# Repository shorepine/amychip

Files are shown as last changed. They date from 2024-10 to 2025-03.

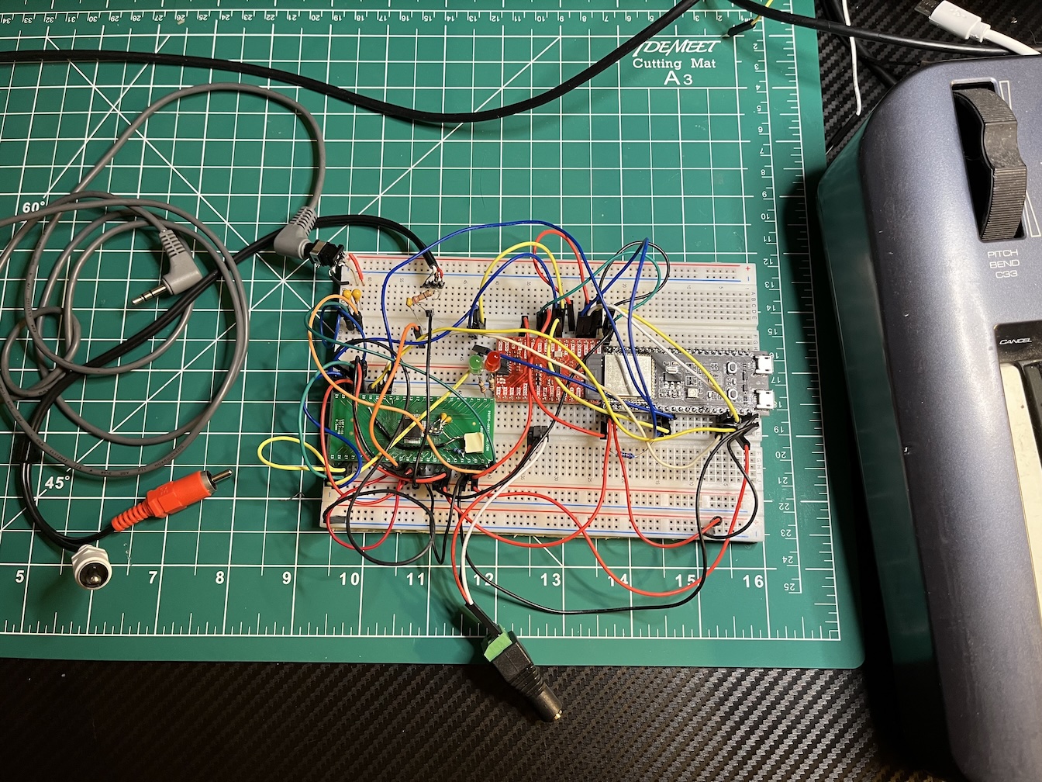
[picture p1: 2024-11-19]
images/pcm9211_hookup.jpeg

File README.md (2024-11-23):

# AMY on a chip 

This repository collects "AMYchip" implementations, where we run the [AMY](https://github.com/shorepine/AMY) synthesizer on a full chip (doing nothing else), servicing requests over i2c (and future, SPI etc).

We have
 - [`esp32s3`](https://github.com/shorepine/amychip/tree/main/esp32s3)

And soon want to have
 - `rp2350`
 - `esp32p4`
 - `daisy`

## How to

Set your I2S and I2C pins at the top of the `amychip.c` in your chip's folder:

```c
#define I2S_BCLK 13 
#define I2S_LRCLK 12
#define I2S_DIN 11 // data going to the codec, eg DAC data
#define I2C_SLAVE_SCL 5  
#define I2C_SLAVE_SDA 4 
#define I2C_MASTER_SCL 17
#define I2C_MASTER_SDA 18
#define I2S_DOUT 16 // data coming from the codec, eg ADC  data
```

Set up your DAC / ADC codec. I'm using the [`WM8960`](https://www.sparkfun.com/products/21250) codec. Wire it up like:

```
Tulip or etc I2C/Mabee/Grove SCL -> I2C_SLAVE_SCL
Tulip or etc I2C/Mabee/Grove SDA -> I2C_SLAVE_SDA
Tulip or etc I2C/Mabee/Grove GND -> MCU GND
Tulip or etc I2C/Mabee/Grove 3.3V -> MCU 3V3
USB 5V -> MCU (we need 5V to power this codec)
WM8960 GND -> Audio in sleeve/GND
WM8960 LINPUT1 -> Audio in L
WM8960 RINPUT1 -> Audio in R
WM8960 HPL -> Audio out L
WM8960 OUT3 -> Audio out sleeve  *** NOTE: Audio-out "ground" is actually a special "mid-voltage" on OUT3
WM8960 HPR -> Audio out R
WM8960 BLCK -> I2S_BCLK
WM8960 DACLRC -> I2S_LRCLK (shared)
WM8960 DACDAT -> I2S_DIN
WM8960 ADCLRC -> I2S_LRCLK (shared)
WM8960 ADCDAT -> I2S_DOUT
WM8960 SCL -> I2C_MASTER_SCL
WM8960 SDA -> I2C_MASTER_SDA
WM8960 3V3 -> MCU 3V3
WM8960 VIN -> MCU 5V 
WM8960 GND -> MCU GND 
```

Compile / flash `amychip` using the instructions in the chip's folder.

Control the chip over I2C. In e.g. Tulip, that's as simple as 

```python
from machine import I2C
import amy
i2c = I2C(0, freq=400000)

amy.override_send= lambda x : i2c.writeto(0x58, bytes(x.encode('ascii')))
amy.send(reset=amy.RESET_TIMEBASE, time=tulip.ticks_ms()) # Restart the clock
```

You can get this on Tulip World:

```python
world.download('amychip.py')
execfile('amychip.py')
```

## Protocol

For now, over i2c, we just send AMY messages encoded as ASCII to `0x58`. Nothing gets returned. 

TODO:
 - ~~`memorypcm` / sample loading~~
 - stderr feedback over I2C
 - `sequencer.c`, sending interrupts to the "main" i2c host
 - SPI? UART?

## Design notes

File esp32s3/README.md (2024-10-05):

# AMY on a chip 

An ESP-IDF implementation of running [AMY](https://github.com/shorepine/AMY) on a full chip 

[See the main README for setup instructions.](https://github.com/shorepine/amychip/blob/main/README.md)

## ESP32-S3 setup

Install and export the [ESP-IDF](https://github.com/espressif/esp-idf). Use the `master` branch.  You will likely need version 5.4; version 5.2 does not work, so install this new version even if you have an existing, older one installed.

```bash
git clone https://github.com/espressif/esp-idf
cd esp-idf
./install.sh esp32s3
source ./export.sh
cd ..
```

Compile and flash your AMY board

```bash
cd amychip
idf.py set-target esp32s3
cd esp32s3
idf.py flash
```

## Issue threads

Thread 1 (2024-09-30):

import amychip fails

phesterman, 2024-09-30:
I successfully built and flashed amychip to my esp32s3.

Then, I followed these instructions:
```
from machine import I2C
import amy
i2c = I2C(0, freq=400000)

amy.override_send= lambda x : i2c.writeto(0x58, bytes(x.encode('ascii')))
```

I downloaded amychip.py from tulip world.

When I import amychip:

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

Where did I mess it up?  (My Tulip is up to date.)

Closed 2024-10-01.

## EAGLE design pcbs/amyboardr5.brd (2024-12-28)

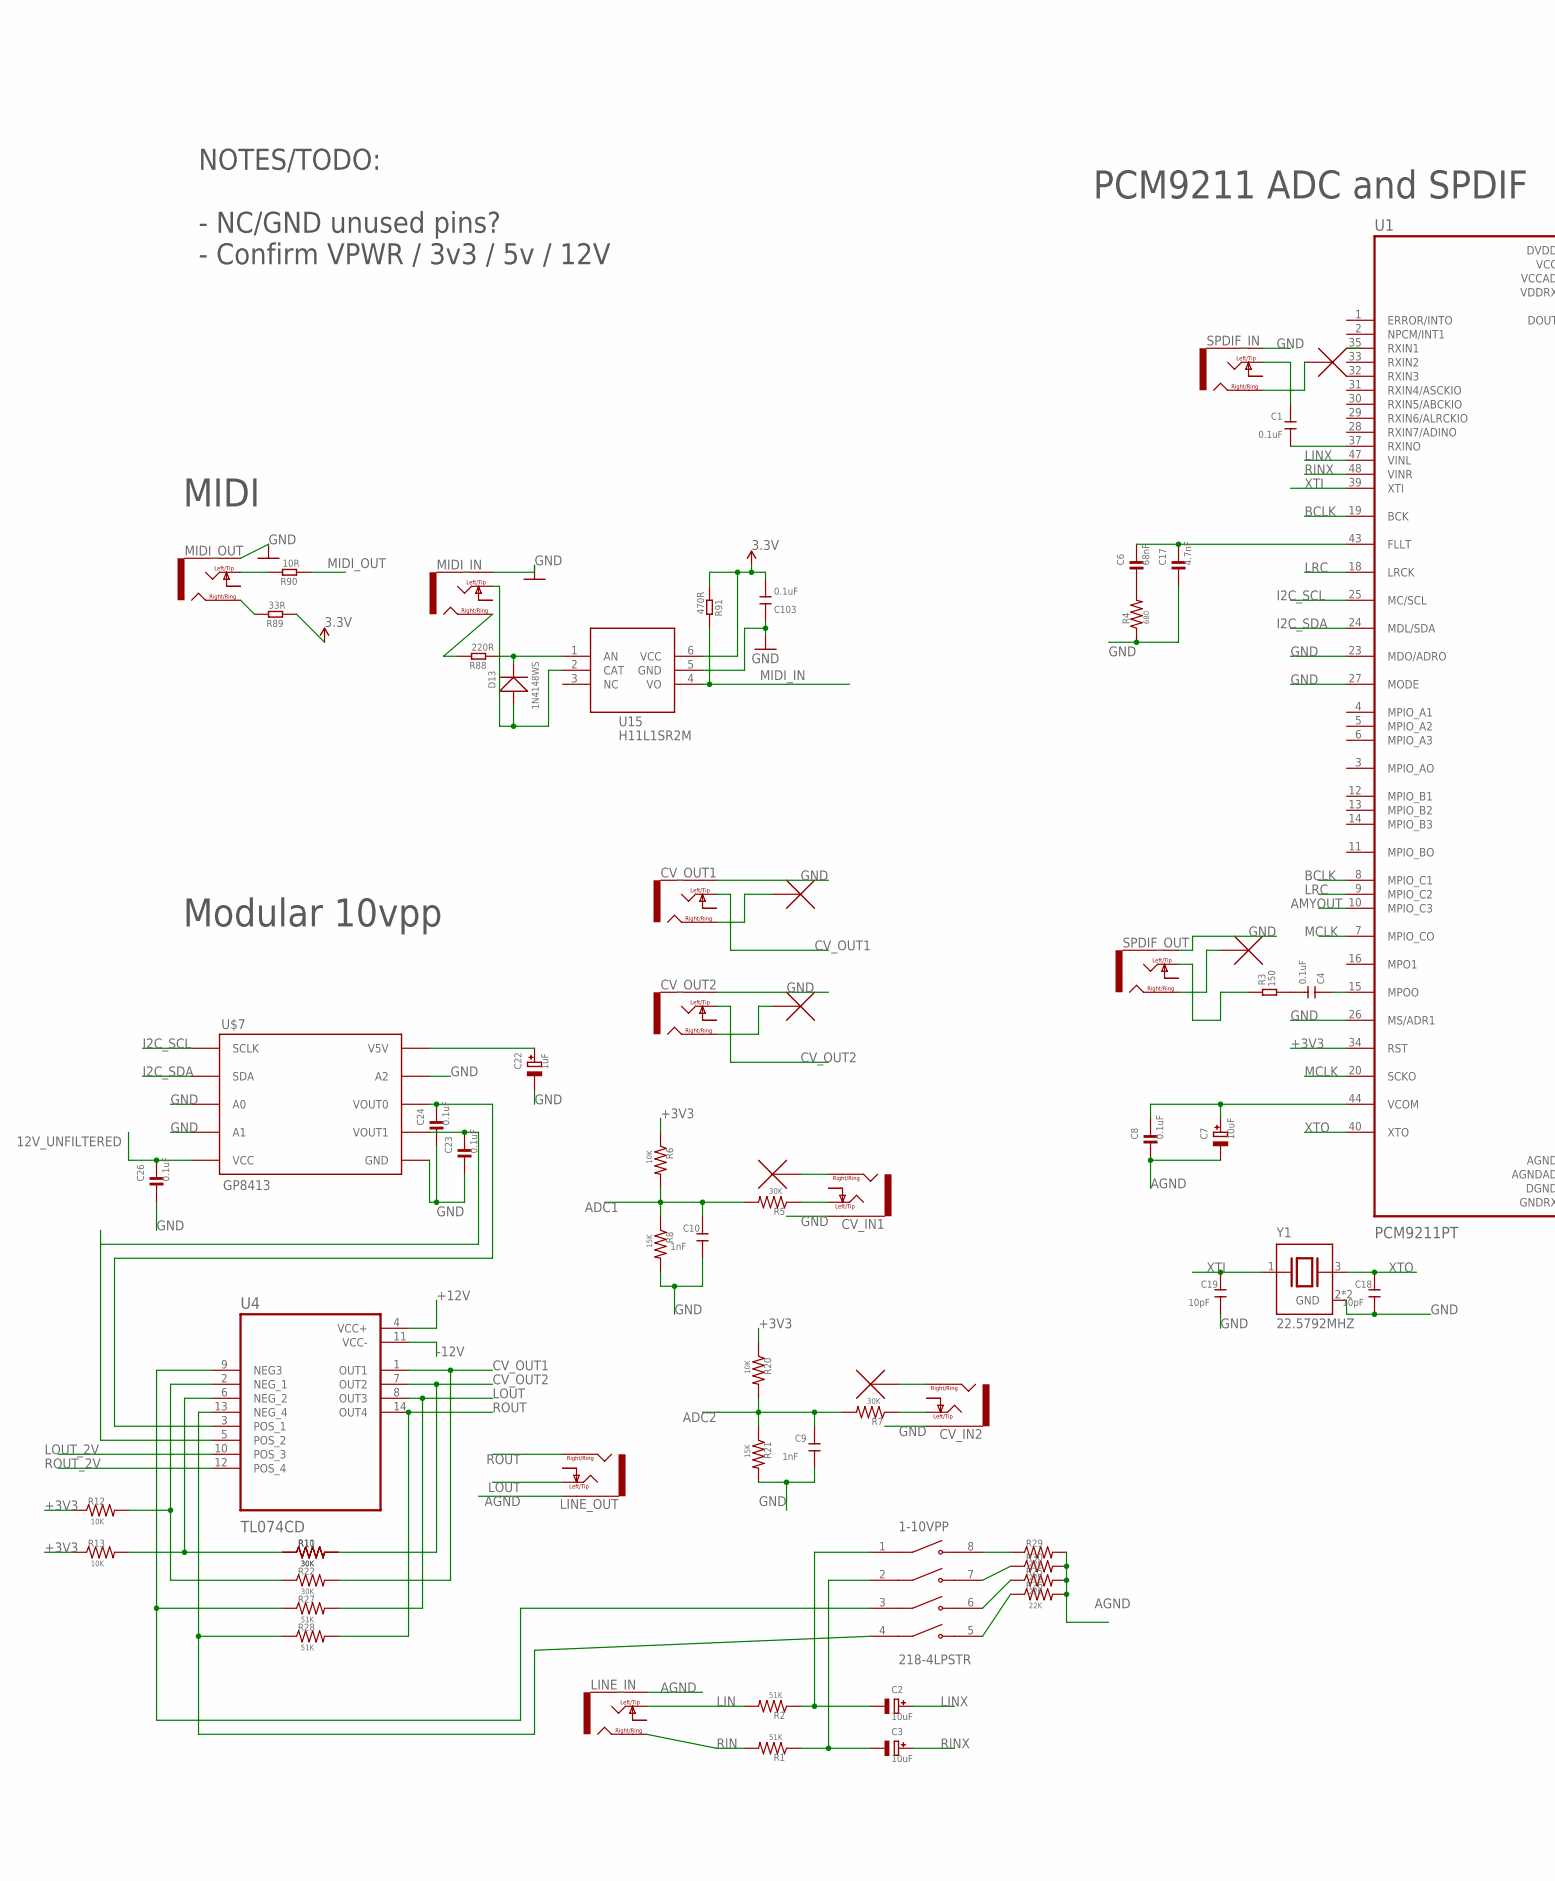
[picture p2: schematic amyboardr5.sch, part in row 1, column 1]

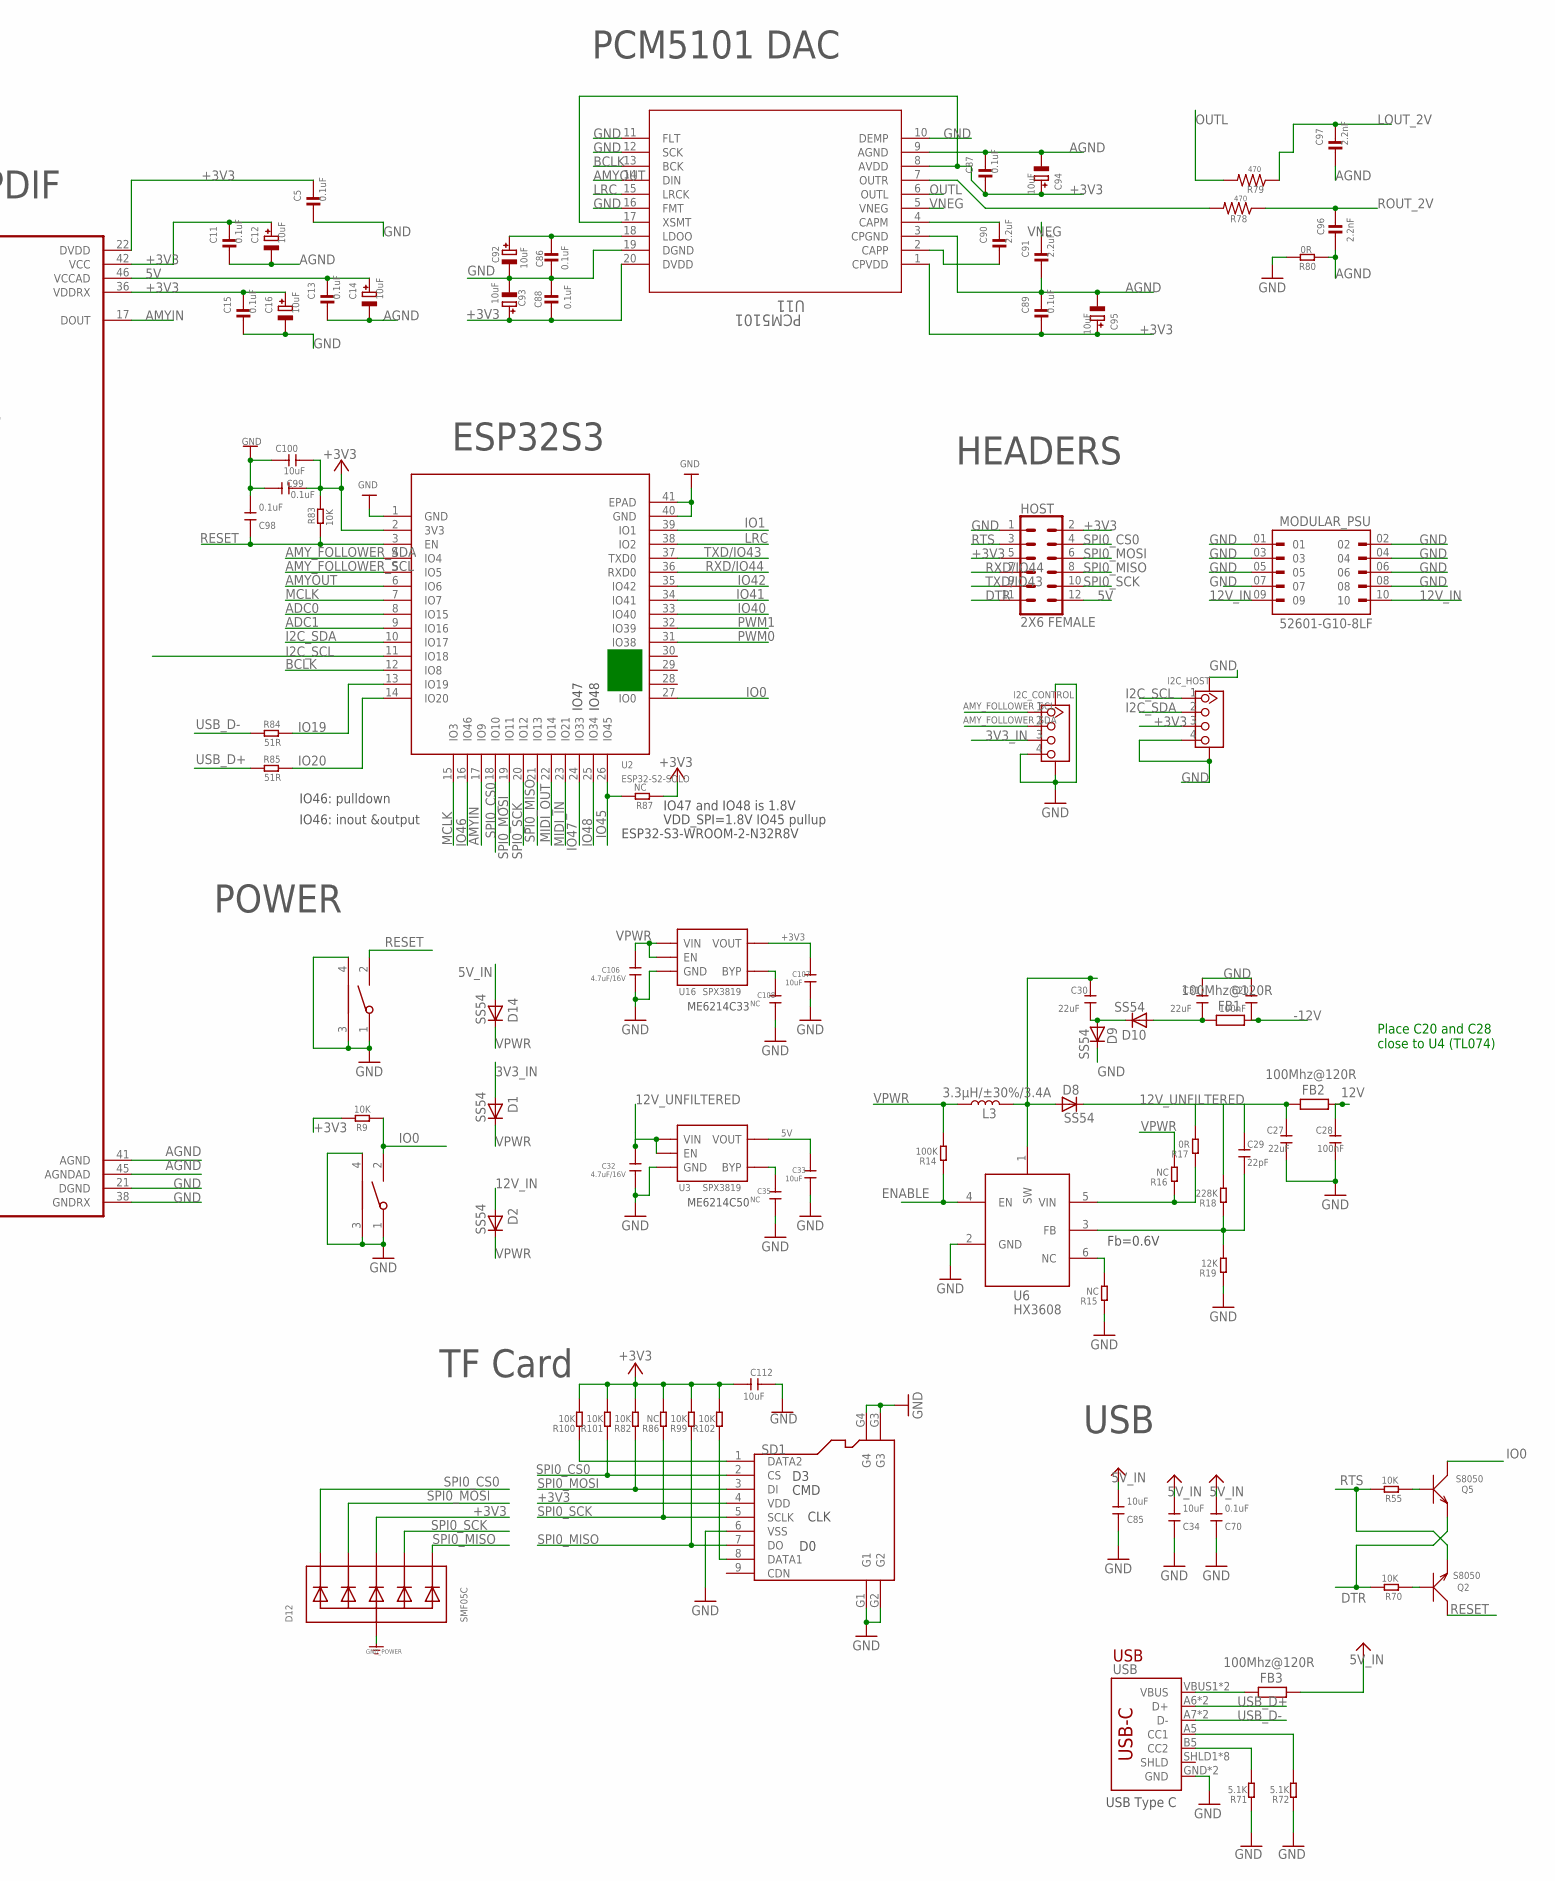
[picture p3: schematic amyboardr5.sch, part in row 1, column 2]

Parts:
1-10VPP: 218-4LPSTR; SW_218-4LPSTR
BOOT: TS24CA; 2*4*3.5MM
C1, C4: 0.1uF; C0603
C2, C3, C7, C12, C14, C16, C92, C93, C94, C95: 10uF; PANASONIC_C
C5, C8, C11, C13, C15, C23, C24, C26, C86, C87, C88, C89: 0.1uF; 0805-NO@1
C6: 68nF; 0805-NO@1
C9, C10: 1nF; C0603
C17: 4.7nF; 0805-NO@1
C18, C19: 10pF; C0603
C20, C28: 100nF; C0603
C22: 1uF; PANASONIC_C
C27, C30, C31: 22uF; C0603
C29: 22pF; C0603
C32, C106: 4.7uF/16V; 0603
C33, C107: 10uF; 0603
C34, C85, C100, C112: 10uF; DISCRETE_C0603
C35, C108: NC; 0603
C70, C98, C99, C103: 0.1uF; DISCRETE_C0603
C90, C91: 2.2uF; 0805-NO@1
C96, C97: 2.2nF; 0805-NO@1
CV_IN1, CV_IN2: NV-PJ3410_STEREO; NV-PJ3410_SOCKET
CV_OUT1, CV_OUT2: NV-PJ3410_STEREO; NV-PJ3410_SOCKET
D1, D2, D8, D9, D10, D14: SS54; DO-214AC
D12: SMF05C; SOT363
D13: 1N4148WS; SOD323
FB1, FB2, FB3: 100Mhz@120R; R0805
HOST: 2X6 FEMALE; 2X6
I2C_CONTROL, I2C_HOST: GROVE-CONNECTOR-SMD'90D'; HW4-SMD-2.0-90D
L3: 3.3µH/±30%/3.4A; CR54
LINE_IN: NV-PJ3410_STEREO; NV-PJ3410_SOCKET
LINE_OUT: NV-PJ3410_STEREO; NV-PJ3410_SOCKET
MIDI_IN: NV-PJ3410_STEREO; NV-PJ3410_SOCKET
MIDI_OUT: NV-PJ3410_STEREO; NV-PJ3410_SOCKET
MODULAR_PSU: 52601-G10-8LF; AMPHENOL_52601-G10-8LF
PCM5101: U11; PW20_TEX
Q2, Q5: S8050; SOT23
R1, R2, R27, R28: 51K; R0805
R3: 150; DISCRETE_R0603
R4: 680; R0805
R5, R7, R10, R11, R22: 30K; R0805
R6, R12, R13, R20: 10K; R0805
R8, R21: 15K; R0805
R9, R55, R70, R83: 10K; R0603
R14: 100K; DISCRETE_R0603
R15, R16, R86: NC; DISCRETE_R0603
R17, R80: 0R; DISCRETE_R0603
R18: 228K; DISCRETE_R0603
R19: 12K; DISCRETE_R0603
R25, R26, R29, R30: 22K; R0805
R71, R72: 5.1K; DISCRETE_R0603
R78, R79: 470; R0805
R82, R99, R100, R101, R102: 10K; DISCRETE_R0603
R84, R85: 51R; R0603
R87: NC; R0603
R88: 220R; R0603
R89: 33R; R0603
R90: 10R; R0603
R91: 470R; R0603
RST: TS24CA; 2*4*3.5MM
SD1: HOLDER-MICROSD-9P; 9P-SMD-W/-RING
SPDIF_IN: NV-PJ3410_STEREO; NV-PJ3410_SOCKET
SPDIF_OUT: NV-PJ3410_STEREO; NV-PJ3410_SOCKET
U1: PCM9211PT; QFP50P900X900X160-48N
U2: ESP32­S2­SOLO; ESP32-­S2-­SOLO
U3, U16: SPX3819; SOT23-5
U4: TL074CD; SOIC127P600X175-14N
U6: HX3608; SOT-23-6
U15: H11L1SR2M; SOP-6-2.54MM
U$7: GP8413; SOIC-10
USB: USB_C5; USB-C-16P-5
Y1: 22.5792MHZ; XTAL_ABM10W-22.5792MHZ-8-K1Z-T3

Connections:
3.3V: C103.2, R89.1, R91.1, U15.6 (VCC)
3V3_IN: D1.A, I2C_CONTROL.3
5V: C13.1, C14.+, C33.1, HOST.12, U1.46 (VCCAD), U3.5 (VOUT)
5V_IN: C34.2, C70.2, C85.2, D14.A, FB3.2
12V: C28.1, FB2.2, R17.2
12V_IN: D2.A, MODULAR_PSU.09, MODULAR_PSU.10
12V_UNFILTERED: C26.1, C27.1, C32.1, D8.C, FB2.1, U3.1 (VIN), U3.3 (EN), U$7.5 (VCC)
+3V3: C5.1, C11.1, C12.+, C15.1, C16.+, C87.2, C88.2, C89.2, C93.+, C94.+, C95.+, C99.1, C100.1, C107.1, C112.2, D12.4 (C3), HOST.2, HOST.5, I2C_HOST.3, PCM5101.1 (CPVDD), PCM5101.8 (AVDD), PCM5101.17 (XSMT), PCM5101.20 (DVDD), R6.1, R9.2, R12.1, R13.1, R20.1, R82.2, R83.2, R86.2, R87.1, R99.2, R100.2, R101.2, R102.2, SD1.4 (VDD), U1.22 (DVDD), U1.34 (RST), U1.36 (VDDRX), U1.42 (VCC), U2.2 (3V3), U16.5 (VOUT)
+12V: U4.4 (VCC+)
-12V: C20.2, FB1.2, U4.11 (VCC-)
ADC0: U2.8 (IO15)
ADC1: C10.1, R5.2, R6.2, R8.1, U2.9 (IO16)
ADC2: C9.1, R7.2, R20.2, R21.1
AGND: C7.-, C8.2, C11.2, C12.-, C13.2, C14.-, C87.1, C89.1, C91.2, C94.-, C95.-, C96.2, C97.2, LINE_IN.GND (EARTH), LINE_OUT.GND (EARTH), PCM5101.3 (CPGND), PCM5101.9 (AGND), R25.2, R26.2, R29.2, R30.2, R80.1, U1.41 (AGND), U1.45 (AGNDAD)
AMYIN: U1.17 (DOUT), U2.17 (IO9)
AMYOUT: PCM5101.14 (DIN), U1.10 (MPIO_C3), U2.6 (IO6)
AMY_FOLLOWER_SCL: I2C_CONTROL.1, U2.5 (IO5)
AMY_FOLLOWER_SDA: I2C_CONTROL.2, U2.4 (IO4)
BCLK: PCM5101.13 (BCK), U1.8 (MPIO_C1), U1.19 (BCK), U2.12 (IO8)
CV_OUT1: CV_OUT1.LEFT/TIP (TIP), R22.2, U4.1 (OUT1)
CV_OUT2: CV_OUT2.LEFT/TIP (TIP), R10.2, R11.2, U4.7 (OUT2)
DTR: HOST.11, Q5.2 (E), R70.2
ENABLE: R14.1, U6.4 (EN)
GND: BOOT.1, BOOT.3, BOOT.4, C5.2, C9.2, C10.2, C15.2, C16.-, C17.2, C18.2, C19.2, C20.1, C22.-, C23.2, C24.2, C26.2, C27.2, C28.2, C31.1, C32.2, C33.2, C34.1, C35.2, C70.1, C85.1, C86.2, C88.1, C92.-, C93.-, C98.2, C99.2, C100.2, C103.1, C106.2, C107.2, C108.2, C112.1, CV_IN1.GND (EARTH), CV_IN2.GND (EARTH), CV_OUT1.GND (EARTH), CV_OUT2.GND (EARTH), D9.C, D12.2 (A), HOST.1, I2C_CONTROL.4, I2C_CONTROL.SS1, I2C_CONTROL.SS2, I2C_HOST.4, I2C_HOST.SS1, I2C_HOST.SS2, MIDI_IN.GND (EARTH), MIDI_OUT.GND (EARTH), MODULAR_PSU.01, MODULAR_PSU.02, MODULAR_PSU.03, MODULAR_PSU.04, MODULAR_PSU.05, MODULAR_PSU.06, MODULAR_PSU.07, MODULAR_PSU.08, PCM5101.10 (DEMP), PCM5101.11 (FLT), PCM5101.12 (SCK), PCM5101.16 (FMT), PCM5101.19 (DGND), R4.1, R8.2, R15.1, R19.1, R21.2, R71.1, R72.1, R80.2, RST.1, RST.3, RST.4, SD1.6 (VSS), SD1.G1, SD1.G2, SD1.G3, SD1.G4, SPDIF_IN.GND (EARTH), SPDIF_OUT.GND (EARTH), U1.21 (DGND), U1.23 (MDO/ADRO), U1.26 (MS/ADR1), U1.27 (MODE), U1.35 (RXIN1), U1.38 (GNDRX), U2.1 (GND), U2.40 (GND), U2.41 (EPAD), U3.2 (GND), U6.2 (GND), U15.5 (GND), U16.2 (GND), U$7.3 (A0), U$7.4 (A1), U$7.6 (GND), U$7.9 (A2), USB.GND, USB.GND2 (GND), Y1.2 (GND), Y1.4 (GND)
I2C_SCL: I2C_HOST.1, U1.25 (MC/SCL), U2.11 (IO18), U$7.1 (SCLK)
I2C_SDA: I2C_HOST.2, U1.24 (MDL/SDA), U2.10 (IO17), U$7.2 (SDA)
IO0: BOOT.2, Q5.3 (C), R9.1, U2.27 (IO0)
IO1: U2.39 (IO1)
IO19: R84.2, U2.13 (IO19)
IO20: R85.2, U2.14 (IO20)
IO40: U2.33 (IO40)
IO41: U2.34 (IO41)
IO42: U2.35 (IO42)
IO45: R87.2, U2.26 (IO45)
IO46: U2.16 (IO46)
IO47: U2.24 (IO33)
IO48: U2.25 (IO34)
LIN: LINE_IN.LEFT/TIP (TIP), R2.2
LINX: C2.+, U1.47 (VINL)
LOUT: LINE_OUT.LEFT/TIP (TIP), R27.2, U4.8 (OUT3)
LOUT_2V: C97.1, R79.1, U4.10 (POS_3)
LRC: PCM5101.15 (LRCK), U1.9 (MPIO_C2), U1.18 (LRCK), U2.38 (IO2)
MCLK: U1.7 (MPIO_CO), U1.20 (SCKO), U2.7 (IO7), U2.15 (IO3)
MIDI_IN: R91.2, U2.23 (IO21), U15.4 (VO)
MIDI_OUT: R90.1, U2.22 (IO14)
unnamed: C1.2, U1.37 (RXINO)
unnamed: C4.2, R3.2
unnamed: C4.1, U1.15 (MPOO)
unnamed: 1-10VPP.1, C2.-, R2.1
unnamed: 1-10VPP.2, C3.-, R1.1
unnamed: C7.+, C8.1, U1.44 (VCOM)
unnamed: C6.1, C17.1, U1.43 (FLLT)
unnamed: C6.2, R4.2
unnamed: CV_IN2.LEFT/TIP (TIP), R7.1
unnamed: C35.1, U3.4 (BYP)
unnamed: C31.2, D10.A, FB1.1
unnamed: C24.1, U4.3 (POS_1), U$7.8 (VOUT0)
unnamed: CV_IN1.LEFT/TIP (TIP), R5.1
unnamed: C23.1, U4.5 (POS_2), U$7.7 (VOUT1)
unnamed: C30.1, D8.A, L3.P$2 (2), U6.1 (SW)
unnamed: C22.+, U$7.10 (V5V)
unnamed: C29.2, R18.1, R19.2, U6.3 (FB)
unnamed: R15.2, U6.6 (NC)
unnamed: R16.1, R17.1, U6.5 (VIN)
unnamed: C30.2, D9.A, D10.C
unnamed: R10.1, R11.1, R13.2, U4.6 (NEG_2)
unnamed: R12.2, R22.1, U4.2 (NEG_1)
unnamed: Q2.1 (B), R70.1
unnamed: 1-10VPP.5, R26.1
unnamed: 1-10VPP.6, R25.1
unnamed: Q5.1 (B), R55.1
unnamed: R72.2, USB.A5 (CC1)
unnamed: R71.2, USB.B5 (CC2)
unnamed: 1-10VPP.8, R29.1
unnamed: 1-10VPP.7, R30.1
unnamed: FB3.1, USB.VBUS1 (VBUS), USB.VBUS2 (VBUS)
unnamed: 1-10VPP.3, R27.1, U4.9 (NEG3)
unnamed: 1-10VPP.4, R28.1, U4.13 (NEG_4)
unnamed: C86.1, C92.+, PCM5101.18 (LDOO)
unnamed: PCM5101.7 (OUTR), R78.2
unnamed: C90.1, PCM5101.4 (CAPM)
unnamed: C90.2, PCM5101.2 (CAPP)
unnamed: D13.+, MIDI_IN.LEFT/TIP (TIP), U15.2 (CAT)
unnamed: MIDI_IN.RIGHT/RING (RING), R88.2
unnamed: D13.-, R88.1, U15.1 (AN)
unnamed: MIDI_OUT.LEFT/TIP (TIP), R90.2
unnamed: MIDI_OUT.RIGHT/RING (RING), R89.2
unnamed: C108.1, U16.4 (BYP)
unnamed: R100.1, SD1.1 (DATA2)
unnamed: R102.1, SD1.8 (DATA1)
OUTL: PCM5101.6 (OUTL), R79.2
PWM0: U2.31 (IO38)
PWM1: U2.32 (IO39)
RESET: C98.1, Q2.3 (C), R83.1, RST.2, U2.3 (EN)
RIN: LINE_IN.RIGHT/RING (RING), R1.2
RINX: C3.+, U1.48 (VINR)
ROUT: LINE_OUT.RIGHT/RING (RING), R28.2, U4.14 (OUT4)
ROUT_2V: C96.1, R78.1, U4.12 (POS_4)
RTS: HOST.3, Q2.2 (E), R55.2
RXD/IO44: HOST.7, U2.36 (RXD0)
SPDIFIN_SIGNAL: C1.1, SPDIF_IN.LEFT/TIP (TIP)
SPDIFOUT_SIGNAL: R3.1, SPDIF_OUT.LEFT/TIP (TIP)
SPI0_CS0: D12.1 (C1), HOST.4, R101.1, SD1.2 (CS), U2.18 (IO10)
SPI0_MISO: D12.6 (C5), HOST.8, R99.1, SD1.7 (DO), U2.21 (IO13)
SPI0_MOSI: D12.3 (C2), HOST.6, R82.1, SD1.3 (DI), U2.19 (IO11)
SPI0_SCK: D12.5 (C4), HOST.10, R86.1, SD1.5 (SCLK), U2.20 (IO12)
TXD/IO43: HOST.9, U2.37 (TXD0)
USB_D+: R85.1, USB.A6 (D+), USB.B6 (D+)
USB_D-: R84.1, USB.A7 (D-), USB.B7 (D-)
VNEG: C91.1, PCM5101.5 (VNEG)
VPWR: C106.1, D1.C, D2.C, D14.C, L3.P$1 (1), R14.2, R16.2, U16.1 (VIN), U16.3 (EN)
XTI: C19.1, U1.39 (XTI), Y1.1
XTO: C18.1, U1.40 (XTO), Y1.3 (2)

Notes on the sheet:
USB
USB Type C
IO46: pulldown
IO46: inout &output
ESP32-S3-WROOM-2-N32R8V
IO47
IO48
IO47 and IO48 is 1.8V
VDD_SPI=1.8V IO45 pullup
POWER
ME6214C33
MIDI
PCM9211 ADC and SPDIF
ESP32S3
HEADERS
NOTES/TODO: - NC/GND unused pins? - Confirm VPWR / 3v3 / 5v / 12V
TF Card
CMD
CLK
Modular 10vpp
Fb=0.6V
ME6214C50
PCM5101 DAC
Place C20 and C28 close to U4 (TL074)

Board: 2 copper layers, 147 parts (11 on the bottom side), 102 nets, no tracks yet.

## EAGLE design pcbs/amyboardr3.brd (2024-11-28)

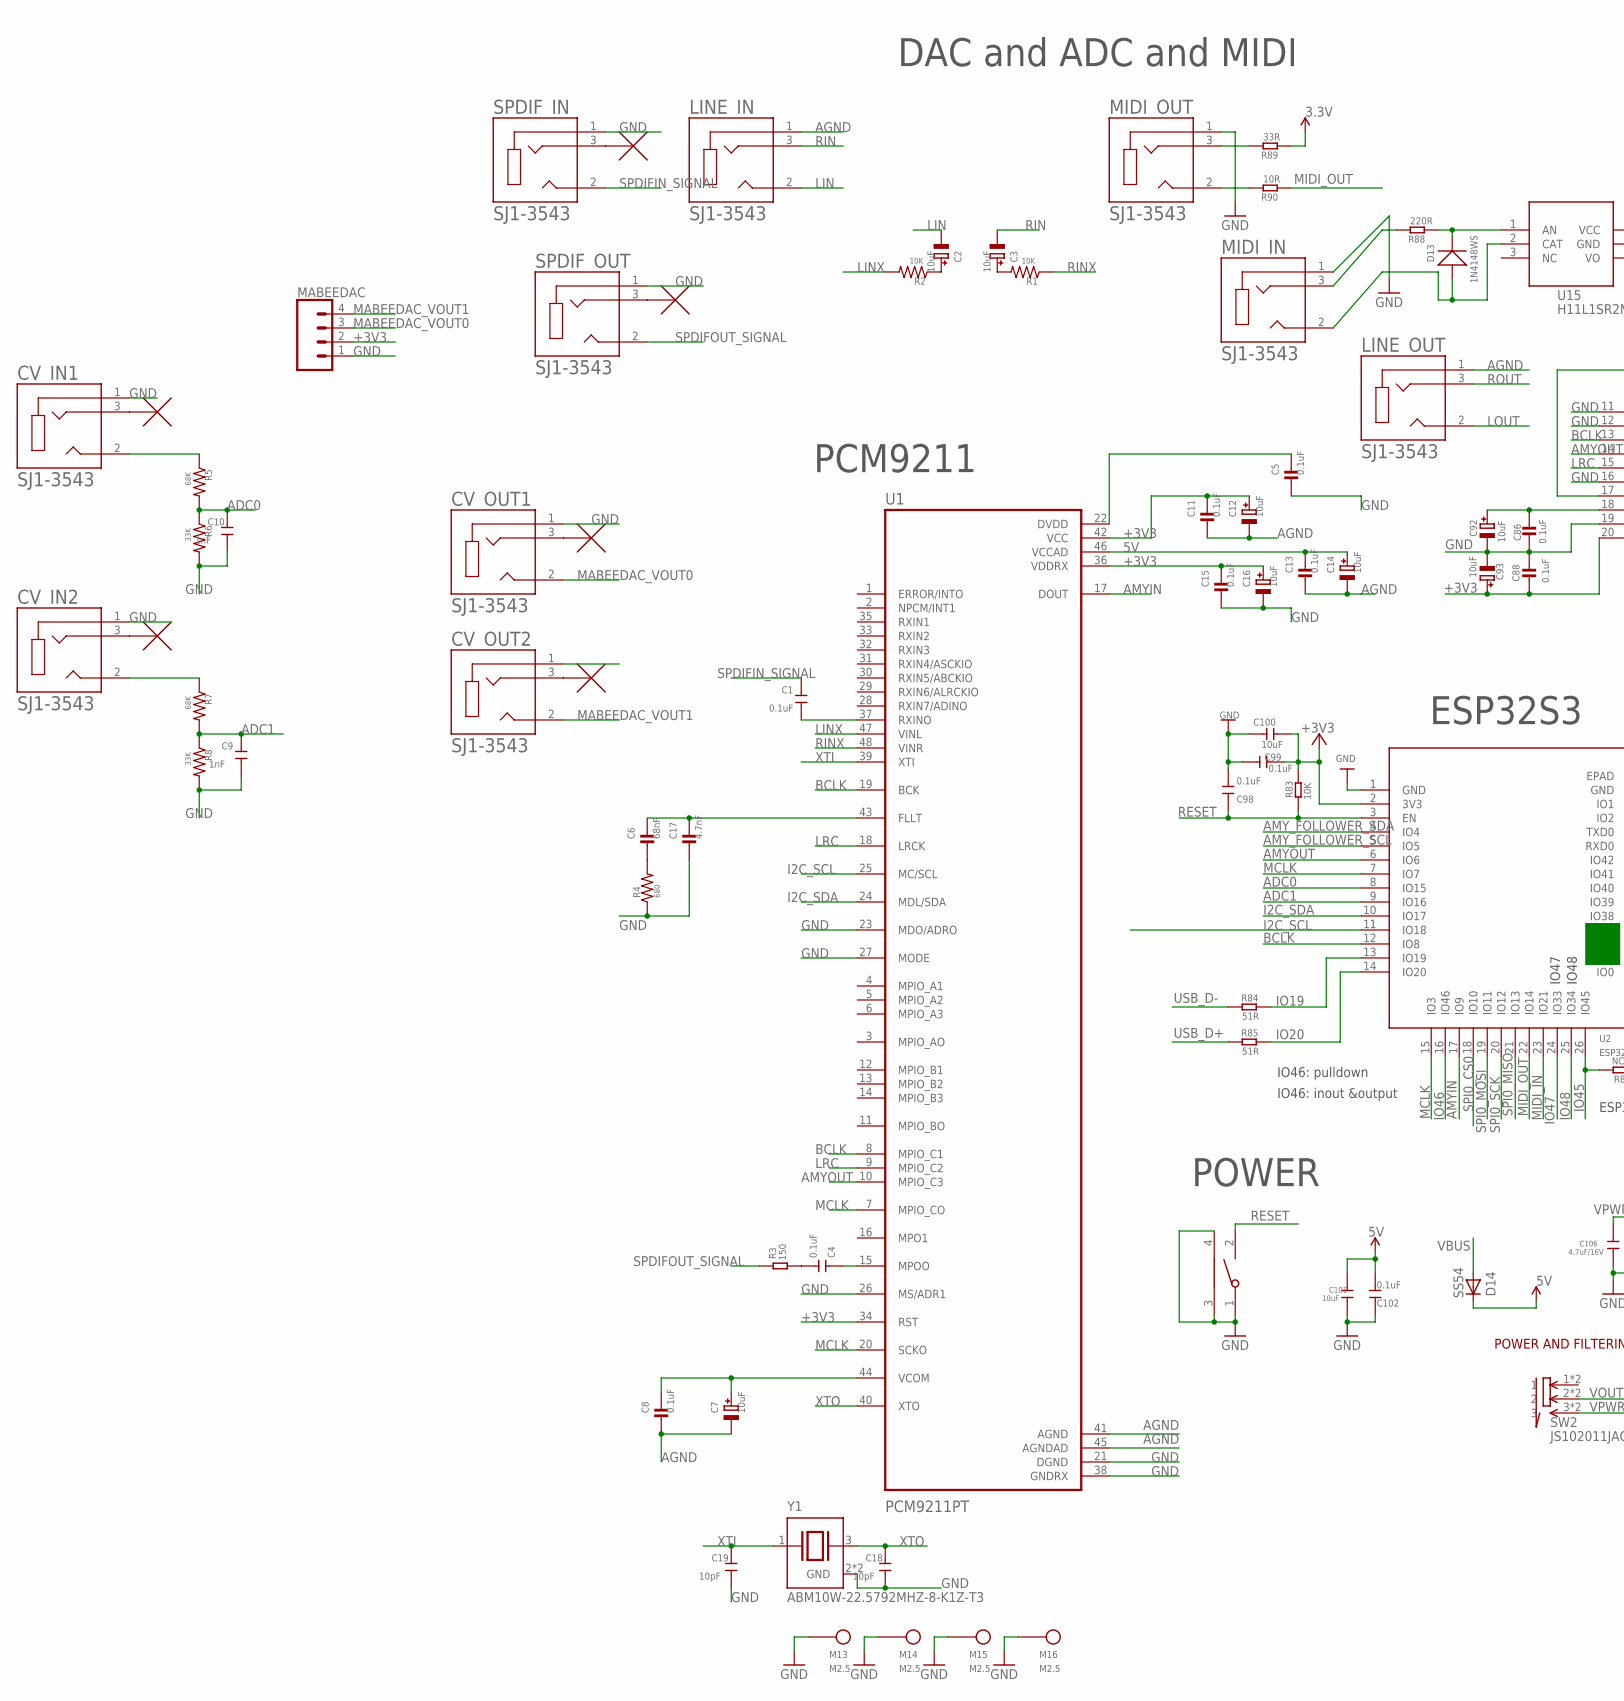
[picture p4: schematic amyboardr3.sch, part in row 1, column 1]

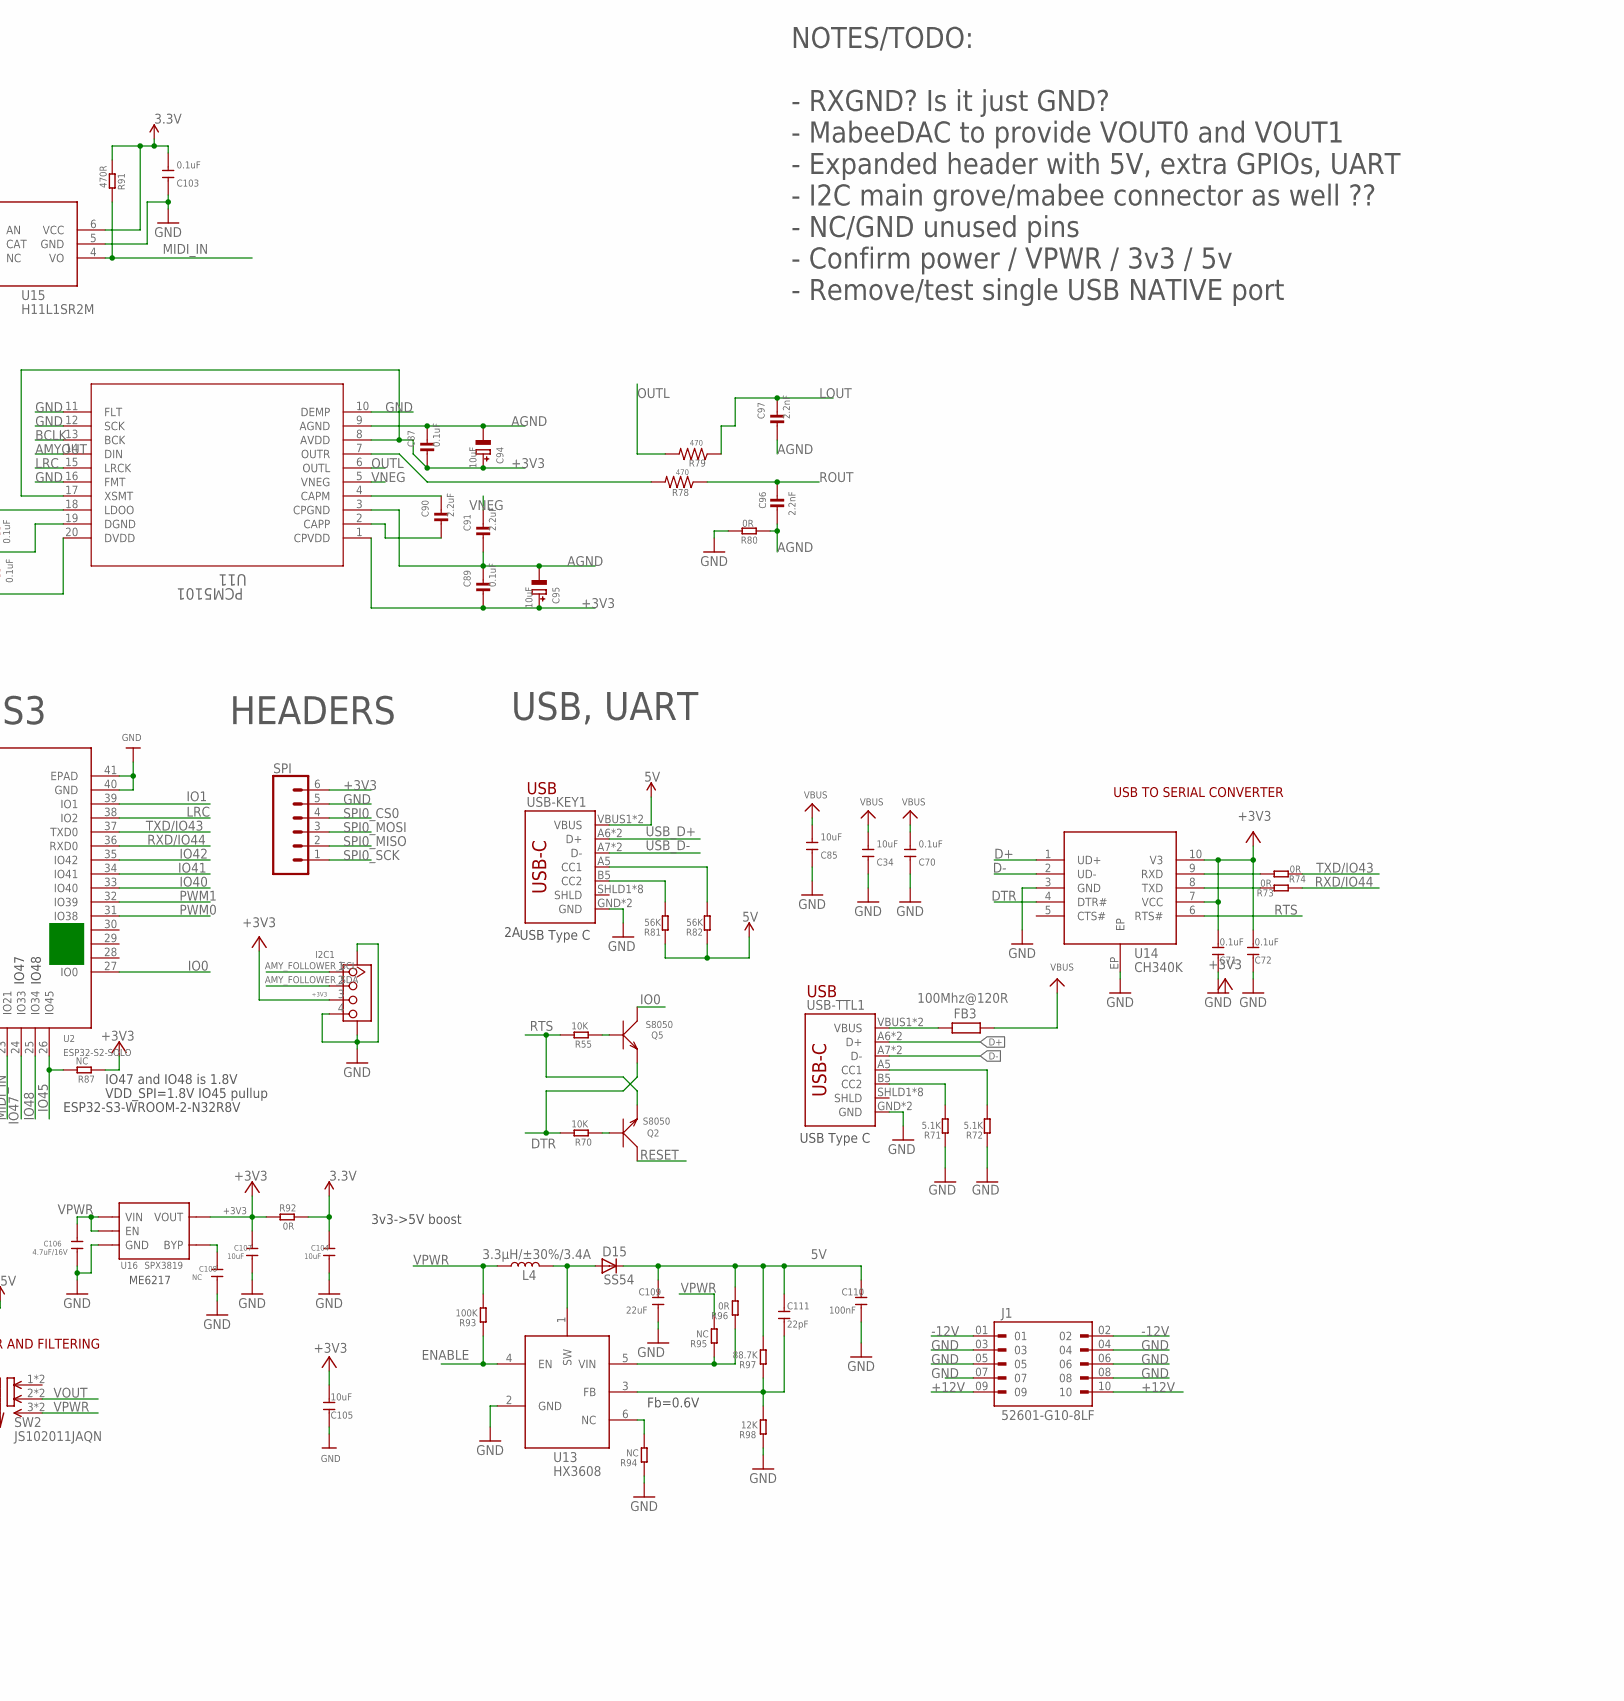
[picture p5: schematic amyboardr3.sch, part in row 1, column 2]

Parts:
C1, C4: 0.1uF; C0603
C2, C3, C7, C12, C14, C16, C92, C93, C94, C95: 10uF; PANASONIC_C
C5, C8, C11, C13, C15, C86, C87, C88, C89: 0.1uF; 0805-NO@1
C6: 68nF; 0805-NO@1
C9, C10: 1nF; C0603
C17: 4.7nF; 0805-NO@1
C18, C19: 10pF; C0603
C34, C85, C100, C105: 10uF; DISCRETE_C0603
C70, C71, C72, C98, C99, C102, C103: 0.1uF; DISCRETE_C0603
C90, C91: 2.2uF; 0805-NO@1
C96, C97: 2.2nF; 0805-NO@1
C101, C104, C107: 10uF; 0603
C106: 4.7uF/16V; 0603
C108: NC; 0603
C109: 22uF; C0603
C110: 100nF; C0603
C111: 22pF; C0603
CV_IN1, CV_IN2: SJ1-3543; CUI_SJ1-3543
CV_OUT1, CV_OUT2: SJ1-3543; CUI_SJ1-3543
D13: 1N4148WS; SOD323
D14, D15: SS54; DO-214AC
FB3: 100Mhz@120R; R0805
I2C1: GROVE-CONNECTOR-SMD'90D'; HW4-SMD-2.0-90D
J1: 52601-G10-8LF; AMPHENOL_52601-G10-8LF
L4: 3.3µH/±30%/3.4A; CR54
LINE_IN: SJ1-3543; CUI_SJ1-3543
LINE_OUT: SJ1-3543; CUI_SJ1-3543
M13, M14, M15, M16: M2.5
MABEEDAC: CONN_04; 1X04
MIDI_IN: SJ1-3543; CUI_SJ1-3543
MIDI_OUT: SJ1-3543; CUI_SJ1-3543
PCM5101: U11; PW20_TEX
Q2, Q5: S8050; SOT23
R1, R2: 10K; R0805
R3: 150; DISCRETE_R0603
R4: 680; R0805
R5, R7: 68K; R0805
R6, R8: 33K; R0805
R55, R70, R83: 10K; R0603
R71, R72: 5.1K; DISCRETE_R0603
R73, R74, R92: 0R; R0603
R78, R79: 470; R0805
R80, R96: 0R; DISCRETE_R0603
R81, R82: 56K; DISCRETE_R0603
R84, R85: 51R; R0603
R87: NC; R0603
R88: 220R; R0603
R89: 33R; R0603
R90: 10R; R0603
R91: 470R; R0603
R93: 100K; DISCRETE_R0603
R94, R95: NC; DISCRETE_R0603
R97: 88.7K; DISCRETE_R0603
R98: 12K; DISCRETE_R0603
RST1: TS24CA; 2*4*3.5MM
SPDIF_IN: SJ1-3543; CUI_SJ1-3543
SPDIF_OUT: SJ1-3543; CUI_SJ1-3543
SPI: CONN_06SILK_FEMALE_PTH; 1X06
SW2: JS102011JAQN; SMD-6-2.5MM
U1: PCM9211PT; QFP50P900X900X160-48N
U2: ESP32­S2­SOLO; ESP32-­S2-­SOLO
U13: HX3608; SOT-23-6
U14: CH340K; ESOP-10-EP-150MIL
U15: H11L1SR2M; SOP-6-2.54MM
U16: SPX3819; SOT23-5
USB-KEY1: USB_C5; USB-C-16P-5
USB-TTL1: USB_C5; USB-C-16P-5
Y1: ABM10W-22.5792MHZ-8-K1Z-T3; XTAL_ABM10W-22.5792MHZ-8-K1Z-T3

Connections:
3.3V: C103.2, C104.1, R89.1, R91.1, R92.2, U15.6 (VCC)
5V: C13.1, C14.+, C101.1, C102.2, C109.1, C110.1, C111.1, D14.C, D15.C, R81.1, R82.1, R96.2, R97.2, U1.46 (VCCAD), USB-KEY1.VBUS1 (VBUS), USB-KEY1.VBUS2 (VBUS)
+3V3: C5.1, C11.1, C12.+, C15.1, C16.+, C71.2, C72.2, C87.2, C88.2, C89.2, C93.+, C94.+, C95.+, C99.1, C100.1, C105.2, C107.1, I2C1.3, MABEEDAC.2, PCM5101.1 (CPVDD), PCM5101.8 (AVDD), PCM5101.17 (XSMT), PCM5101.20 (DVDD), R83.2, R87.1, R92.1, SPI.6, U1.22 (DVDD), U1.34 (RST), U1.36 (VDDRX), U1.42 (VCC), U2.2 (3V3), U14.7 (VCC), U14.10 (V3), U16.5 (VOUT)
+12V: J1.09, J1.10
-12V: J1.01, J1.02
ADC0: C10.1, R5.2, R6.1, U2.8 (IO15)
ADC1: C9.1, R7.2, R8.1, U2.9 (IO16)
AGND: C7.-, C8.2, C11.2, C12.-, C13.2, C14.-, C87.1, C89.1, C91.2, C94.-, C95.-, C96.2, C97.2, LINE_IN.1, LINE_OUT.1, PCM5101.3 (CPGND), PCM5101.9 (AGND), R80.1, U1.41 (AGND), U1.45 (AGNDAD)
AMYIN: U1.17 (DOUT), U2.17 (IO9)
AMYOUT: PCM5101.14 (DIN), U1.10 (MPIO_C3), U2.6 (IO6)
AMY_FOLLOWER_SCL: I2C1.1, U2.5 (IO5)
AMY_FOLLOWER_SDA: I2C1.2, U2.4 (IO4)
BCLK: PCM5101.13 (BCK), U1.8 (MPIO_C1), U1.19 (BCK), U2.12 (IO8)
D+: U14.1 (UD+), USB-TTL1.A6 (D+), USB-TTL1.B6 (D+)
D-: U14.2 (UD-), USB-TTL1.A7 (D-), USB-TTL1.B7 (D-)
DTR: Q5.2 (E), R70.2, U14.4 (DTR#)
ENABLE: R93.1, U13.4 (EN)
GND: C5.2, C9.2, C10.2, C15.2, C16.-, C17.2, C18.2, C19.2, C34.1, C70.1, C71.1, C72.1, C85.1, C86.2, C88.1, C92.-, C93.-, C98.2, C99.2, C100.2, C101.2, C102.1, C103.1, C104.2, C105.1, C106.2, C107.2, C108.2, C109.2, C110.2, CV_IN1.1, CV_IN2.1, CV_OUT1.1, I2C1.4, I2C1.SS1, I2C1.SS2, J1.03, J1.04, J1.05, J1.06, J1.07, J1.08, M13.1, M14.1, M15.1, M16.1, MABEEDAC.1, MIDI_IN.1, MIDI_OUT.1, PCM5101.10 (DEMP), PCM5101.11 (FLT), PCM5101.12 (SCK), PCM5101.16 (FMT), PCM5101.19 (DGND), R4.1, R6.2, R8.2, R71.1, R72.1, R80.2, R94.1, R98.1, RST1.1, RST1.3, RST1.4, SPDIF_IN.1, SPDIF_OUT.1, SPI.5, U1.21 (DGND), U1.23 (MDO/ADRO), U1.26 (MS/ADR1), U1.27 (MODE), U1.38 (GNDRX), U2.1 (GND), U2.40 (GND), U2.41 (EPAD), U13.2 (GND), U14.3 (GND), U14.EP, U15.5 (GND), U16.2 (GND), USB-KEY1.GND, USB-KEY1.GND2 (GND), USB-TTL1.GND, USB-TTL1.GND2 (GND), Y1.2 (GND), Y1.4 (GND)
I2C_SCL: U1.25 (MC/SCL), U2.11 (IO18)
I2C_SDA: U1.24 (MDL/SDA), U2.10 (IO17)
IO0: Q5.3 (C), U2.27 (IO0)
IO1: U2.39 (IO1)
IO19: R84.2, U2.13 (IO19)
IO20: R85.2, U2.14 (IO20)
IO40: U2.33 (IO40)
IO41: U2.34 (IO41)
IO42: U2.35 (IO42)
IO45: R87.2, U2.26 (IO45)
IO46: U2.16 (IO46)
IO47: U2.24 (IO33)
IO48: U2.25 (IO34)
LIN: C2.-, LINE_IN.2
LINX: R2.2, U1.47 (VINL)
LOUT: C97.1, LINE_OUT.2, R79.1
LRC: PCM5101.15 (LRCK), U1.9 (MPIO_C2), U1.18 (LRCK), U2.38 (IO2)
MABEEDAC_VOUT0: CV_OUT1.2, MABEEDAC.3
MABEEDAC_VOUT1: CV_OUT2.2, MABEEDAC.4
MCLK: U1.7 (MPIO_CO), U1.20 (SCKO), U2.7 (IO7), U2.15 (IO3)
MIDI_IN: R91.2, U2.23 (IO21), U15.4 (VO)
MIDI_OUT: R90.1, U2.22 (IO14)
unnamed: C1.2, U1.37 (RXINO)
unnamed: C4.2, R3.2
unnamed: C4.1, U1.15 (MPOO)
unnamed: C2.+, R2.1
unnamed: C3.+, R1.2
unnamed: C7.+, C8.1, U1.44 (VCOM)
unnamed: C6.1, C17.1, U1.43 (FLLT)
unnamed: C6.2, R4.2
unnamed: CV_IN1.2, R5.1
unnamed: CV_IN2.2, R7.1
unnamed: Q2.1 (B), R70.1
unnamed: Q5.1 (B), R55.1
unnamed: R72.2, USB-TTL1.A5 (CC1)
unnamed: R71.2, USB-TTL1.B5 (CC2)
unnamed: R74.2, U14.9 (RXD)
unnamed: R73.2, U14.8 (TXD)
unnamed: FB3.1, USB-TTL1.VBUS1 (VBUS), USB-TTL1.VBUS2 (VBUS)
unnamed: C86.1, C92.+, PCM5101.18 (LDOO)
unnamed: PCM5101.7 (OUTR), R78.2
unnamed: C90.1, PCM5101.4 (CAPM)
unnamed: C90.2, PCM5101.2 (CAPP)
unnamed: R82.2, USB-KEY1.A5 (CC1)
unnamed: R81.2, USB-KEY1.B5 (CC2)
unnamed: D13.+, MIDI_IN.2, U15.2 (CAT)
unnamed: MIDI_IN.3, R88.2
unnamed: D13.-, R88.1, U15.1 (AN)
unnamed: MIDI_OUT.2, R90.2
unnamed: MIDI_OUT.3, R89.2
unnamed: C108.1, U16.4 (BYP)
unnamed: D15.A, L4.P$2 (2), U13.1 (SW)
unnamed: C111.2, R97.1, R98.2, U13.3 (FB)
unnamed: R94.2, U13.6 (NC)
unnamed: R95.1, R96.1, U13.5 (VIN)
OUTL: PCM5101.6 (OUTL), R79.2
PWM0: U2.31 (IO38)
PWM1: U2.32 (IO39)
RESET: C98.1, Q2.3 (C), R83.1, RST1.2, U2.3 (EN)
RIN: C3.-, LINE_IN.3
RINX: R1.1, U1.48 (VINR)
ROUT: C96.1, LINE_OUT.3, R78.1
RTS: Q2.2 (E), R55.2, U14.6 (RTS#)
RXD/IO44: R73.1, U2.36 (RXD0)
SPDIFIN_SIGNAL: C1.1, SPDIF_IN.2
SPDIFOUT_SIGNAL: R3.1, SPDIF_OUT.2
SPI0_CS0: SPI.4, U2.18 (IO10)
SPI0_MISO: SPI.2, U2.21 (IO13)
SPI0_MOSI: SPI.3, U2.19 (IO11)
SPI0_SCK: SPI.1, U2.20 (IO12)
TXD/IO43: R74.1, U2.37 (TXD0)
USB_D+: R85.1, USB-KEY1.A6 (D+), USB-KEY1.B6 (D+)
USB_D-: R84.1, USB-KEY1.A7 (D-), USB-KEY1.B7 (D-)
VBUS: C34.2, C70.2, C85.2, D14.A, FB3.2
VNEG: C91.1, PCM5101.5 (VNEG)
VOUT: SW2.2, SW2.2@1 (2)
VPWR: C106.1, L4.P$1 (1), R93.2, R95.2, SW2.3, SW2.3@1 (3), U16.1 (VIN), U16.3 (EN)
XTI: C19.1, U1.39 (XTI), Y1.1
XTO: C18.1, U1.40 (XTO), Y1.3 (2)

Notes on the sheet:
USB
USB TO SERIAL CONVERTER
USB, UART
USB Type C
IO46: pulldown
IO46: inout &output
ESP32-S3-WROOM-2-N32R8V
IO47
IO48
IO47 and IO48 is 1.8V
VDD_SPI=1.8V IO45 pullup
POWER AND FILTERING
POWER
ME6217
Fb=0.6V
3v3->5V boost
DAC and ADC and MIDI
PCM9211
ESP32S3
HEADERS
NOTES/TODO: - RXGND? Is it just GND? - MabeeDAC to provide VOUT0 and VOUT1 - Expanded header with 5V, extra GPIOs, UART - I2C main grove/mabee connector as well ?? - NC/GND unused pins - Confirm power / VPWR / 3v3 / 5v - Remove/test single USB NATIVE port

Board: 2 copper layers, 121 parts (5 on the bottom side), 88 nets, no tracks yet.

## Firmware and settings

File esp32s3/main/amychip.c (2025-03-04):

#include <stdio.h>
#include <inttypes.h>
#include "sdkconfig.h"
#include "freertos/FreeRTOS.h"
#include "freertos/task.h"
#include "esp_chip_info.h"
#include "esp_flash.h"
#include "esp_system.h"
#include "esp_task.h"
#include "driver/i2c_master.h"

#include "amy.h"
#include "examples.h"
#include "freertos/queue.h"
#include "freertos/event_groups.h"
#include "esp_log.h"
#include "esp_err.h"

#include "driver/i2s_std.h"

static const char *TAG = "amy-chip";

i2s_chan_handle_t tx_handle;
i2s_chan_handle_t rx_handle;

#ifdef AMYBOARD_DIY
#define I2S_MCLK  10
#define I2S_BCLK  13 
#define I2S_LRCLK 12
#define AMYOUT 11 // data going to the codec, eg DAC data
#define I2C_SLAVE_SCL 5  
#define I2C_SLAVE_SDA 4 
#define I2C_MASTER_SCL 17
#define I2C_MASTER_SDA 18
#define AMYIN 16 // data coming from the codec, eg ADC  data
#elif defined AMYBOARD_R3
// stuff in the eagle
#define I2S_MCLK  3
#define I2S_BCLK  8
#define I2S_LRCLK 2
#define AMYOUT 6 // data going to the codec, eg DAC data
#define I2C_SLAVE_SCL 5
#define I2C_SLAVE_SDA 4 
#define I2C_MASTER_SCL 18
#define I2C_MASTER_SDA 17
#define AMYIN 9 // data coming from the codec, eg ADC  data
#define MPIO 7 // we don't know what this is, but that's the pin it's connected to 
#endif

#define I2S_SAMPLE_TYPE I2S_BITS_PER_SAMPLE_32BIT
typedef int32_t i2s_sample_type;



// mutex that locks writes to the delta queue
SemaphoreHandle_t xQueueSemaphore;

void delay_ms(uint32_t ms) {
    vTaskDelay(ms / portTICK_PERIOD_MS);
}

// Task handles for the renderers, multicast listener and main
TaskHandle_t amy_render_handle;
TaskHandle_t alles_fill_buffer_handle;


#define ALLES_TASK_COREID (1)
#define ALLES_RENDER_TASK_COREID (0)
#define ALLES_FILL_BUFFER_TASK_COREID (1)
#define ALLES_RENDER_TASK_PRIORITY (ESP_TASK_PRIO_MAX-1 )
#define ALLES_FILL_BUFFER_TASK_PRIORITY (ESP_TASK_PRIO_MAX-1)
#define ALLES_TASK_NAME             "alles_task"
#define ALLES_RENDER_TASK_NAME      "alles_r_task"
#define ALLES_FILL_BUFFER_TASK_NAME "alles_fb_task"
#define ALLES_TASK_STACK_SIZE    (8 * 1024) 
#define ALLES_RENDER_TASK_STACK_SIZE (8 * 1024)
#define ALLES_FILL_BUFFER_TASK_STACK_SIZE (8 * 1024)


// i2c stuff
#define I2C_CLK_FREQ 400000
#include "esp32-hal-i2c-slave.h"
#define DATA_LENGTH 255
#define _I2C_NUMBER(num) I2C_NUM_##num
#define I2C_NUMBER(num) _I2C_NUMBER(num)
#define I2C_SLAVE_NUM I2C_NUMBER(1) /*!< I2C port number for slave dev */
#define I2C_SLAVE_TX_BUF_LEN (2 * DATA_LENGTH)              /*!< I2C slave tx buffer size */
#define I2C_SLAVE_RX_BUF_LEN (2 * DATA_LENGTH)              /*!< I2C slave rx buffer size */
#define AMYCHIP_ADDR 0x58
#define PCM9211_ADDR 0x40
#define I2C_MASTER_NUM I2C_NUMBER(0) /*!< I2C port number for master dev */
#define I2C_MASTER_TX_BUF_DISABLE 0                           /*!< I2C master doesn't need buffer */
#define I2C_MASTER_RX_BUF_DISABLE 0  

i2c_master_bus_handle_t tool_bus_handle;
i2c_master_dev_handle_t pcm9211_handle;
#define I2C_TOOL_TIMEOUT_VALUE_MS (500)

esp_err_t i2c_master_write(uint8_t device_addr, uint8_t *data_wr, size_t size_wr) {
    esp_err_t ret = i2c_master_transmit(pcm9211_handle, data_wr, size_wr, I2C_TOOL_TIMEOUT_VALUE_MS);
    if (ret == ESP_OK) {
        //ESP_LOGI(TAG, "Write OK");
    } else if (ret == ESP_ERR_TIMEOUT) {
        ESP_LOGW(TAG, "Bus is busy");
    } else {
        ESP_LOGW(TAG, "Write Failed");
    }
    return 0;
}

uint8_t pcm9211_readRegister(uint8_t reg) {
    uint8_t buf[1] = {reg};
    uint8_t buffer[1] = { 0};
    ESP_ERROR_CHECK(i2c_master_transmit_receive(pcm9211_handle, buf, 1, buffer, 1, I2C_TOOL_TIMEOUT_VALUE_MS));
    return(buffer[0]);
}

void pcm9211_writeRegister(uint8_t reg, uint16_t value) {
  uint8_t data[2];
  data[0] = reg; 
  data[1] = value; 
  if (i2c_master_write(PCM9211_ADDR, data, 2))
      fprintf(stderr, "bad write to pcm9211\n");
}

uint8_t pcm9211_registers[10][2] = {
    { 0x40, 0x33 }, // Power down ADC, power down DIR, power down DIT, power down OSC
    { 0x40, 0xc0 }, // Normal operation for all
    { 0x34, 0x00 }, // Initialize DIR - both biphase amps on, input from RXIN0
    { 0x26, 0x01 }, // Main Out is DIR/ADC if no DIR sync (these match power-on default, repeated for clarity).
    { 0x6B, 0x00 }, // Main output pins are DIR/ADC AUTO
    { 0x30, 0x04 }, // PLL sends 512fs as SCK
    { 0x31, 0x0A }, // XTI SCK as 512fs too
    { 0x60, 0x44 }, // Initialize PCM9211 DIT to send SPDIF from AUXIN1 through MPO0 (pin15).  MPO1 (pin16) is VOUT (Valid)
    { 0x78, 0x3d }, // MPO0 = 0b1101 = TXOUT, MPO1 = 0b0011 = VOUT
    { 0x6F, 0x40 }  // MPIO_A = CLKST etc / MPIO_B = AUXIN2 / MPIO_C = AUXIN1
};

esp_err_t setup_pcm9211(void) {
    for(uint8_t i=0;i<10; i++) {
        delay_ms(100);
        fprintf(stderr, "[pcm9211] setting register 0x%02x to 0x%02x: ", pcm9211_registers[i][0], pcm9211_registers[i][1]);
        pcm9211_writeRegister(pcm9211_registers[i][0], pcm9211_registers[i][1]);
        delay_ms(100);
        uint8_t read_back = pcm9211_readRegister(pcm9211_registers[i][0]);
        if(read_back == pcm9211_registers[i][1]) {
            fprintf(stderr, "success\n");
        } else {
            fprintf(stderr, "failed?: read back is 0x%02x\n", read_back);
        }
    }
    return ESP_OK;
}

static esp_err_t i2c_master_init(void) {
    i2c_master_bus_config_t i2c_bus_config = {
        .clk_source = I2C_CLK_SRC_DEFAULT,
        .i2c_port = I2C_MASTER_NUM,
        .scl_io_num = I2C_MASTER_SCL,
        .sda_io_num = I2C_MASTER_SDA,
        .flags.enable_internal_pullup = true,
    };

    if (i2c_new_master_bus(&i2c_bus_config, &tool_bus_handle) != ESP_OK) {
        return 1;
    }
    i2c_device_config_t i2c_dev_conf = {
        .scl_speed_hz = I2C_CLK_FREQ,
        .device_address = PCM9211_ADDR, 
        .flags.disable_ack_check = true,
    };
    if (i2c_master_bus_add_device(tool_bus_handle, &i2c_dev_conf, &pcm9211_handle) != ESP_OK) {
        return 1;
    }
    return ESP_OK;
}



static void i2c_slave_request_cb(uint8_t num, uint8_t *cmd, uint8_t cmd_len, void * arg) {
    if (cmd_len > 0) {
        // first write to master
        i2cSlaveWrite(I2C_SLAVE_NUM, cmd, cmd_len, 0);
    } else {
        // cmd_len == 0 means master want more data from slave
        // we just send one byte 0 each time to master here
        uint8_t extra_data = 0x00;
        i2cSlaveWrite(I2C_SLAVE_NUM, &extra_data, 1, 0);
    }
}

static void i2c_slave_receive_cb(uint8_t num, uint8_t * data, size_t len, bool stop, void * arg) {
    if (len > 0) {
        data[len]= 0;
        amy_play_message((char*)data);
    }
}

static esp_err_t i2c_slave_init(void) {
    i2cSlaveAttachCallbacks(I2C_SLAVE_NUM, i2c_slave_request_cb, i2c_slave_receive_cb, NULL);
    return i2cSlaveInit(I2C_SLAVE_NUM, I2C_SLAVE_SDA, I2C_SLAVE_SCL, AMYCHIP_ADDR, I2C_CLK_FREQ, I2C_SLAVE_RX_BUF_LEN, I2C_SLAVE_TX_BUF_LEN);
}



// AMY synth states
extern struct state amy_global;
extern uint32_t event_counter;
extern uint32_t message_counter;

void esp_show_debug(uint8_t t) {

}

// Render the second core
void esp_render_task( void * pvParameters) {
    while(1) {
        ulTaskNotifyTake(pdTRUE, portMAX_DELAY);
        amy_render(0, AMY_OSCS/2, 1);
        xTaskNotifyGive(alles_fill_buffer_handle);
    }
}

extern int16_t amy_in_block[AMY_BLOCK_SIZE * AMY_NCHANS];
i2s_sample_type my_int32_block[AMY_BLOCK_SIZE * AMY_NCHANS];

// Make AMY's FABT run forever , as a FreeRTOS task 
void esp_fill_audio_buffer_task() {
    size_t read = 0;
    size_t written = 0;
    while(1) {
        AMY_PROFILE_START(AMY_ESP_FILL_BUFFER)
        i2s_channel_read(rx_handle, my_int32_block, AMY_BLOCK_SIZE * sizeof(i2s_sample_type) * AMY_NCHANS, &read, portMAX_DELAY);
        
        for (int i = 0; i < AMY_BLOCK_SIZE * AMY_NCHANS; ++i)
            amy_in_block[i] = (i2s_sample_type)(my_int32_block[i] >> 16);

        
        // Get ready to render
        amy_prepare_buffer();

        // Tell the other core to start rendering
        xTaskNotifyGive(amy_render_handle);
        // Render me

        amy_render(AMY_OSCS/2, AMY_OSCS, 0);

        // Wait for the other core to finish
        ulTaskNotifyTake(pdTRUE, portMAX_DELAY);

        // Write to i2s
        int16_t *block = amy_fill_buffer();
        for (int i = 0; i < AMY_BLOCK_SIZE * AMY_NCHANS; ++i)
            my_int32_block[i] = ((i2s_sample_type)block[i]) << 16;


        AMY_PROFILE_STOP(AMY_ESP_FILL_BUFFER)

        i2s_channel_write(tx_handle, my_int32_block, AMY_BLOCK_SIZE * sizeof(i2s_sample_type) * AMY_NCHANS, &written, portMAX_DELAY);

        if(written != AMY_BLOCK_SIZE * sizeof(i2s_sample_type) * AMY_NCHANS || read != AMY_BLOCK_SIZE * sizeof(i2s_sample_type) * AMY_NCHANS) {
            fprintf(stderr,"i2s underrun: [w %d,r %d] vs %d\n", written, read, AMY_BLOCK_SIZE * sizeof(i2s_sample_type) * AMY_NCHANS);
        }

    }
}



// init AMY from the esp. wraps some amy funcs in a task to do multicore rendering on the ESP32 
amy_err_t esp_amy_init() {
    amy_start(2, 1, 1, 1);
    // We create a mutex for changing the event queue and pointers as two tasks do it at once
    xQueueSemaphore = xSemaphoreCreateMutex();

    // Create the second core rendering task
    xTaskCreatePinnedToCore(&esp_render_task, ALLES_RENDER_TASK_NAME, ALLES_RENDER_TASK_STACK_SIZE, NULL, ALLES_RENDER_TASK_PRIORITY, &amy_render_handle, ALLES_RENDER_TASK_COREID);

    // Wait for the render tasks to get going before starting the i2s task
    delay_ms(100);

    // And the fill audio buffer thread, combines, does volume & filters
    xTaskCreatePinnedToCore(&esp_fill_audio_buffer_task, ALLES_FILL_BUFFER_TASK_NAME, ALLES_FILL_BUFFER_TASK_STACK_SIZE, NULL, ALLES_FILL_BUFFER_TASK_PRIORITY, &alles_fill_buffer_handle, ALLES_FILL_BUFFER_TASK_COREID);

    return AMY_OK;
}


// Setup I2S
amy_err_t setup_i2s(void) {
    i2s_chan_config_t chan_cfg = I2S_CHANNEL_DEFAULT_CONFIG(I2S_NUM_AUTO, I2S_ROLE_SLAVE);  // ************* I2S_ROLE_SLAVE - needs external I2S clock input.
    i2s_new_channel(&chan_cfg, &tx_handle, &rx_handle);

     i2s_std_config_t std_cfg = {
        .clk_cfg = {
            .sample_rate_hz = 48000,
            .clk_src = I2S_CLK_SRC_EXTERNAL,
            .ext_clk_freq_hz = 48000 * 512,
            .mclk_multiple = 512, 
        },
        .slot_cfg = {
            .data_bit_width = I2S_DATA_BIT_WIDTH_32BIT,
            .slot_bit_width = I2S_SLOT_BIT_WIDTH_32BIT,
            .slot_mode = I2S_SLOT_MODE_STEREO,
            .slot_mask = I2S_STD_SLOT_BOTH,
            .ws_width = 32,
            .ws_pol = false, // false in STD_PHILIPS macro
            .bit_shift = false, // true for STD_PHILIPS macro, but that results in *2* bits delay of dout vs lrclk in Follower mode. false gives 1 bit delay, as expected for i2s.
            .left_align = false,
            .big_endian = false,
            .bit_order_lsb = false,
        },
        .gpio_cfg = {
            .mclk = I2S_MCLK, 
            .bclk = I2S_BCLK,
            .ws = I2S_LRCLK,
            .dout = AMYOUT,
            .din = AMYIN,
            .invert_flags = {
                .mclk_inv = false,
                .bclk_inv = true, // invert bclk for pcm9211 
                .ws_inv = false,
            },
        },
    };

    /* Initialize the channel */
    i2s_channel_init_std_mode(tx_handle, &std_cfg);
    i2s_channel_init_std_mode(rx_handle, &std_cfg);

    /* Before writing data, start the TX channel first */
    i2s_channel_enable(tx_handle);
    i2s_channel_enable(rx_handle);
    return AMY_OK;
}

void app_main(void)
{
    printf("Welcome to the AMY chip implementation!\n");

    /* Print chip information */
    esp_chip_info_t chip_info;
    uint32_t flash_size;
    esp_chip_info(&chip_info);
    printf("This is %s chip with %d CPU core(s), %s%s%s%s, ",
           CONFIG_IDF_TARGET,
           chip_info.cores,
           (chip_info.features & CHIP_FEATURE_WIFI_BGN) ? "WiFi/" : "",
           (chip_info.features & CHIP_FEATURE_BT) ? "BT" : "",
           (chip_info.features & CHIP_FEATURE_BLE) ? "BLE" : "",
           (chip_info.features & CHIP_FEATURE_IEEE802154) ? ", 802.15.4 (Zigbee/Thread)" : "");

    unsigned major_rev = chip_info.revision / 100;
    unsigned minor_rev = chip_info.revision % 100;
    printf("silicon revision v%d.%d, ", major_rev, minor_rev);
    if(esp_flash_get_size(NULL, &flash_size) != ESP_OK) {
        printf("Get flash size failed");
        return;
    }

    printf("%" PRIu32 "MB %s flash\n", flash_size / (uint32_t)(1024 * 1024),
           (chip_info.features & CHIP_FEATURE_EMB_FLASH) ? "embedded" : "external");

    printf("Minimum free heap size: %" PRIu32 " bytes\n", esp_get_minimum_free_heap_size());

    check_init(&i2c_master_init, "i2c_master");
    check_init(&i2c_slave_init, "i2c_slave");
    check_init(&setup_pcm9211, "pcm9211");

    delay_ms(1000);
    

    // make this 1 if you want to actually turn on i2s... it is currently hanging as it can't find MCLK on the pin....
    if(1) {
        check_init(&setup_i2s, "i2s");
        esp_amy_init();
        amy_reset_oscs();

        struct event e = amy_default_event();
        e.time = amy_sysclock();
        e.freq_coefs[0] = 440;
        e.wave = SINE;
        e.osc = 0;
        e.velocity = 1;
        amy_add_event(e);
        //example_voice_chord(amy_sysclock(), 0);
    }
    while(1) {
        delay_ms(1000);
            fprintf(stderr, "register 0x39 is 0x%02x\n", pcm9211_readRegister(0x39));


    }
}

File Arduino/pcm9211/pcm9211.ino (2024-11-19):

// pcm9211
// Basic test of PCM9211 ADC / digital audio transceiver chip.
// dan.ellis@gmail.com 2024-11-15

#include "Wire.h"

// Amychip main I2C config.
static int I2C_DA_PIN = 18;
static int I2C_CK_PIN = 17;


static int PCM9211_ADDRESS = 0x40;  // strap selectable 0x40..0x43

class PCM9211 {
  public:
    bool begin(TwoWire *wireInstance = &Wire) {
      i2c = wireInstance;
    }
    int read_register(int reg) {
      Wire.beginTransmission(PCM9211_ADDRESS);
	    Wire.write(reg);
     	Wire.endTransmission();

	    Wire.requestFrom(PCM9211_ADDRESS, 1);
     	return Wire.read();
    }
    void write_register(int reg, int value) {
      Wire.beginTransmission(PCM9211_ADDRESS);
	    Wire.write(reg);
	    Wire.write(value);
	    Wire.endTransmission();
    }
  protected:
    TwoWire *i2c = NULL;
};

void init_pcm9211(PCM9211 &pcm9211) {
// From https://e2e.ti.com/support/audio-group/audio/f/audio-forum/1370260/pcm9211-pll-not-getting-a-lock-with-audio-input

// Here is a script that you can use and get the system initialize and get it  to work.


// #**************************************
// #this script is for SPDIF-->RXIN0-->DIR-->MainOutput, Record sound from SPDIF to PC through TAS1020

// #So
// #1, Chose RXIN0 to DIR
// #2, Active DIR
// #3, chose DIR output as Mainoutput's source.

// #Also HW modification
// #1, Flying to High Level(3.3V) to make sure U7's output is Hi-Z
// #or 2, TAS1020 output logic high on P1.2 I2S enable signal. 
// #**************************************


// #System RST Control
// #w 80 40 00
// w 80 40 33
pcm9211.write_register(0x40, 0x33);  // Power down ADC, power down DIR, power down DIT, power down OSC
// w 80 40 C0
pcm9211.write_register(0x40, 0xC0);  // Normal operation for all

// #XTI Source, Clock (SCK/BCK/LRCK) Frequency Setting
// # XTI 24.5760 for SCLK 12.288 and BCK 3.072, LRCK 48k = XTI/512
// w 80 31 1A
pcm9211.write_register(0x31, 0x1a);
// w 80 33 22
pcm9211.write_register(0x33, 0x22);
// w 80 20 00
pcm9211.write_register(0x20, 0x00);
// w 80 24 00
pcm9211.write_register(0x24, 0x00);
// #ADC clock source is chosen by REG42
// w 80 26 81
pcm9211.write_register(0x26, 0x81);

// #XTI Source, Secondary Bit/LR Clock (SBCK/SLRCK) Frequency Setting
// w 80 33 22
pcm9211.write_register(0x33, 0x22);

// #*********************************************************
// #-------------------------------Start DIR settings---------------------------------------
// #REG. 21h, DIR Receivable Incoming Biphase's Sampling Frequency Range Setting
// w 80 21 00
pcm9211.write_register(0x21, 0x10);   // 0x10 = normal, 28-108 kHz

// #REG. 22h, DIR CLKSTP and VOUT delay
// w 80 22 01
pcm9211.write_register(0x22, 0x01);

// #REG. 23h, DIR OCS start up wait time and Process for Parity Error Detection and ERROR Release Wait Time Setting
// w 80 23 04
pcm9211.write_register(0x23, 0x04);

// # REG 27h DIR Acceptable fs Range Setting & Mask
// w 80 27 00
//pcm9211.write_register(0x27, 0xd7);  // 0xd7: Limit to 32, 44, 48 +/- 2%
pcm9211.write_register(0x27, 0x00);  // 0xd7: Limit to 32, 44, 48 +/- 2%

// # REG 2Fh, DIR Output Data Format, 24bit I2S mode
// w 80 2F 04
pcm9211.write_register(0x2f, 0x04);

// # REG. 30h, DIR Recovered System Clock (SCK) Ratio Setting
// w 80 30 02
pcm9211.write_register(0x30, 0x02);

// #REG. 32h, DIR Source, Secondary Bit/LR Clock (SBCK/SLRCK) Frequency Setting
// w 80 32 22
pcm9211.write_register(0x32, 0x22);

// #REG 34h DIR Input Biphase Signal Source Select and RXIN01 Coaxial Amplifier
// #--PWR down amplifier, Select RXIN2
// #w 80 34 C2
// #--PWR up amplifier, select RXIN0
// w 80 34 00
//pcm9211.write_register(0x34, 0x00);
// #--PWR up amplifier, select RXIN1
// #w 80 34 01
pcm9211.write_register(0x34, 0x01);

// #REG. 37h, Port Sampling Frequency Calculator Measurement Target Setting, Cal and DIR Fs
// w 80 37 00
pcm9211.write_register(0x37, 0x00);
// #REG 38h rd DIR Fs
// r 80 38 01
pcm9211.write_register(0x38, 0x01);
// #***********************************************************
// #------------------------------------ End DIR settings------------------------------------------


// #***********************************************************
// #---------------------------------Start  MainOutput Settings--------------------------------------
// #MainOutput
// #REG. 6Ah, Main Output & AUXOUT Port Control
// w 80 6A 00
pcm9211.write_register(0x6a, 0x00);

// #REG. 6Bh, Main Output Port (SCKO/BCK/LRCK/DOUT) Source Setting
// w 80 6B 11
//pcm9211.write_register(0x6b, 0x11);  // 0x11 = locked to DIR (0x00 for ADC/DIR auto)
pcm9211.write_register(0x6b, 0x00);  // 0x11 = locked to DIR (0x00 for ADC/DIR auto)

// #REG. 6Dh, MPIO_B & Main Output Port Hi-Z Control
// w 80 6D 00
pcm9211.write_register(0x6d, 0x00);
// #***********************************************************
// #------------------------------------ End MainOutput settings------------------------------------------

// # read back all registers to ensure GUI integrity
// r 80 20 5E
}

// #************** WM8960 setup *****************************

extern "C" {
#include "wm8960.h"

static int WM8690_ADDRESS = 0x1a;

void i2c_master_write_wm8960(uint8_t *data_wr, size_t size_wr) {
  // Register is already encoded into data_wr[0]
  Wire.beginTransmission(WM8690_ADDRESS);
  for (int i = 0; i < size_wr; ++i) {
    Wire.write(data_wr[i]);
  }
  Wire.endTransmission();
}
}

// #***********************************************************


class PCM9211 pcm9211;

void setup() {
  Serial.begin(115200);
  Wire.begin(I2C_DA_PIN, I2C_CK_PIN);
  //pcm9211.begin(&Wire);
  delay(1000);
  Serial.println("Scanning for I2C devices ...");
  int address = 0x40;
  Wire.beginTransmission(address);
  int error = Wire.endTransmission();
  if (error == 0){
    Serial.printf("I2C device found at address 0x%02X\n", address);
  } else if(error != 2){
    Serial.printf("Error %d at address 0x%02X\n", error, address);
  }

  // Default DAC setup
  setup_wm8960_i2s();

  // Configure ADC for 16 bit output
  //pcm9211.write_register(0x48, 0x00);  // ADFMT1:0 = 00 24 bit i2s
  //pcm9211.write_register(0x48, 0x03);  // ADFMT1:0 = 11 16 bit right-justified
  init_pcm9211(pcm9211);
}

void loop() {
  delay(5000);

  Serial.println("Reading 9211 ...");
  // Serial.print("reg 0x38 fscalc rslt=");
  // Serial.println(pcm9211.read_register(0x38), 16);
  // Serial.print("reg 0x39 biphsf rslt=");
  // Serial.println(pcm9211.read_register(0x39), 16);
  Serial.print("reg 0x25 errcause rslt=");
  //Serial.println(pcm9211.read_register(0x25), 16);
}

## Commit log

2024-10-05 Draw attention to audio out GND is *not* GND
2024-10-05 Seems you need to cd into esp32s3 before idf.py flash.
2024-11-06 adding pcbs
    [amyboard.brd, amyboard.sch]
2024-11-19 Added pcm9211.txt with hookup information for dpwe PCM9211 ADC/SPDIF_IO devboard.
2024-11-19 pcm9211: Added description of dpwe devboard wiring. Added PCM9211 Arduino test sketch.
2024-11-23 esp-idf i2c pcm9211 setup
2024-11-25 i2s not working, but reads registers and sets up i2s follower like the espressif test case does..
    [amychip.c]
2024-11-26 adding start of amyboard schematic
    [amyboardr3.brd, amyboardr3.sch]
2024-11-26 deleting old amyboard rev
    [amyboard.sch]
2024-11-27 Added caps and PLL filter to schematic.
2024-11-27 remving eagle cruft
    [amyboardr3.brd]
2024-11-27 moving to 3.5mm jacks for everything
    [amyboardr3.brd, amyboardr3.sch]
2024-11-28 stacked audio jacks
    [amyboardr3.brd, amyboardr3.sch]
2024-11-28 header, fixed adcs
    [amyboardr3.brd, amyboardr3.sch]
2024-11-30 adding r4 board with no UART chip and sd card
    [amyboardr4.brd, amyboardr4.sch]
2024-11-30 moving around
    [amyboardr4.brd, amyboardr4.sch]
2024-12-02 r4 with top jacks
    [amyboardr4.brd, amyboardr4.sch]
2024-12-07 moving jacks together on bottom
    [amyboardr4.brd, amyboardr4.sch]
2024-12-09 adding parts for amyboard
    [amyboardr4.brd, amyboardr4.sch]
2024-12-10 Added 8413, TL074, DIP switch, +/-12V rails to schematic.
    [amyboardr4.brd, amyboardr4.sch]
2024-12-11 removing other boost
    [amyboardr4.brd, amyboardr4.sch]
2024-12-11 4 way DIN, VPWR
    [amyboardr4.brd, amyboardr4.sch]
2024-12-11 copying to r5
    [amyboardr5.brd, amyboardr5.sch]
2024-12-11 adding back in dan's r4
    [amyboardr4.brd, amyboardr4.sch]
2024-12-11 CVOUT fixes
    [amyboardr5.brd, amyboardr5.sch]
2024-12-11 dans fixes
    [amyboardr5.brd, amyboardr5.sch]
2024-12-11 ADC cap in parallel
    [amyboardr5.brd, amyboardr5.sch]
2024-12-11 right side up
    [amyboardr5.sch]
2024-12-11 moving parts
    [amyboardr5.brd]
2024-12-27 Added ferrite beads in Pi circuits to + and -12v lines.
    [amyboardr5.brd, amyboardr5.sch]
2024-12-28 Moved GP8413 and 5V LDO to +12V_UNFILTERED.
    [amyboardr5.brd, amyboardr5.sch]
2024-12-28 copying usb fb
    [amyboardr5.brd, amyboardr5.sch]
2025-03-04 fixes so it builds/runs on AMYboard v0
    [partitions.csv]

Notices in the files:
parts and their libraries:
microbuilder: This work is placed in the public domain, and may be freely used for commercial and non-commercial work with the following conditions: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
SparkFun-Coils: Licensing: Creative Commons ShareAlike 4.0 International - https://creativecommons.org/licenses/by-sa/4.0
